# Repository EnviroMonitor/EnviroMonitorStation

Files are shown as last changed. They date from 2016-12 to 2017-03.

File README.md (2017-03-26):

# EnviroMonitorStation
EnviroMonitorStation (part of Smogly aka EnviroMonitor project) is an ESP8266 based, outdoor environmental monitoring station. It includes temperature, humidity, barometric pressure and most importantly, PM2.5, PM10 dust monitoring.

Features:
- PM1.0, PM2.5, PM10 monitoring
- temperature, humidity, barometric pressure monitoring
- heater for exsiccating incoming air for better results in humid conditions (e.g. during autumn and winter)
- post data to custom backend
- post data to Wunderground
- OTA updates for software
- WiFi auto configuration
- 12V/5V powered

Currently EnviroMonitor station is DIY project, we don't provide ability to buy monitoring station, you need to build it yourself.
We also designed [PCB](https://github.com/EnviroMonitor/EnviroMonitorElectronics) and [enclosure](https://github.com/EnviroMonitor/EnviroMonitorEnclosure) so you can easily build your own sensor. Moreover - every piece of the project is Open Source, so you can modify it for your needs.

Please stay tuned, this is work in progress. Prototypes are being tested and we will post usable software and HW design soon.

# Hardware

## Bill of Materials
Below is the list of parts you will need to build monitoring station:

- Wemos D1 mini ESP8266 based development board (example: https://goo.gl/nk0Xvn)
- PMS3003 - Plantower particulate matter sensor detecting PM1.0, PM2.5, PM10 (example: https://goo.gl/ZB6P51)
- BME280 - barometric pressure, temperature and humidity sensor (example: https://goo.gl/bCfaJp)
- Si7021 temperature and humidity sensors (example: https://goo.gl/RCU0Vk)
- DHT22 temperature and humidity sensors (example: https://goo.gl/guQqyB)
- 12V or 5V heat plate (example: https://goo.gl/Pexr5R)
- DC-DC step down power supply module, preferably based on LM2596 (example: https://goo.gl/TbNs1Y)
- AC power supply with 12V DC 1A output (example: https://goo.gl/fVu5LT)
- N-MOSFET, example: AUIRLZ44Z
- 2.54 pitch male pin headers: 2 x 8 pins (Wemos connectors, usually included with Wemos), 1 x 6 pins (PMS3003 connector), 3 x 3 pins (DS, DHT and HEAT DC switch), 1 x 4 pins (I2C bus)
- 2.54 ptich female pin headers: 2 x 8 pins for wemos socket, 1 x 6 pin (to solder instead of original PMS3003 plug)
- 3 x 3.5 mm pitch 2 pin screw terminals
- resistors: 1 x 4.7 kΩ, 1 x 47 kΩ, 1 x 1 kΩ
- [PCB](https://github.com/EnviroMonitor/EnviroMonitorElectronics)
- [enclosure](https://github.com/EnviroMonitor/EnviroMonitorEnclosure)

# Software
## Backend configuration
Before sensor is added to the system, it needs to be registered on the backend side. After registration you will receive couple of parameters:
- sensor ID - used to identify the sensor
- API key - to be able to post and receive data from backend

## Sensor configuration
After sensor is connected to power, it start local AccessPoint for initial configuration. User needs to connect to this AccessPoint and as a next step, familiar HotSpot configuration page should be presented. Using this simple page user can configure:
- sensor ID (generated during sensor registration)
- API access key (generated during sensor registration)
- WiFi network and password to use for sending data
- backend and OTA server address

Once you finish configuration, sensor will reboot, and join configured WiFi network. If there was any error , e.g. wrong password, sensor will again reboot into AccessPoint mode, so you are able to correct configuration.

## How we measure parameters
In every cycle device measures couple of parameters and sends them to EnviroMonitorWe backend. In current version of hardware we measure:
- PM1.0, PM2.5 and PM10
- external temperature and humidity
- external barometric pressure
- temperature and humidity of air incoming to PMS3003 sensor

Before we start measuring PM* parameters, we ensure that incoming air is of accepted parameters: it's humidity and temperature are acceptable. This is required because humid air particles have size similar to PM1 and PM2.5 and can impact precision of measurement. To overcome this effect one could try to figure out how humidity and temperature impacts the measurement (develop mathematical function) or heat the air. We decided to incorporate heating plate near PMS3003 air intake.

Once the air reaches accepted humidity level, we start PM* measurement. Raw data is then sent to backend using simple HTTP GET call. For every monitoring station we can apply individual calibration functions before data is presented.

## Software updates
Every sensor can be updated over-the-air. Once a day sensor sends special request to backend asking for new compiled software image. Using combination of hardware versions and software version for given hardware backend decides to send new image to sensor over HTTP.
Before applying new image we launch pre-update functions ensuring that even if update goes wrong, sensor is safe, e.g. we switch off the heater. Once the update is successful, we use post-update function to get back all sensor features.

# Development
EnviroMonitor project is developed as a community and open source / open hardware project. We use Github for all the development workflow.
EnviroMonitorStation is Arduino based project, but we use [PlatformIO](http://platformio.org/) development environment. Please follow PlatformIO [getting started guide](http://platformio.org/get-started) to set up your environment. We try too keep our code Arduino compatible, so it's possible to use Arduino IDE for development, but we strongly recommend using PlatformIO.

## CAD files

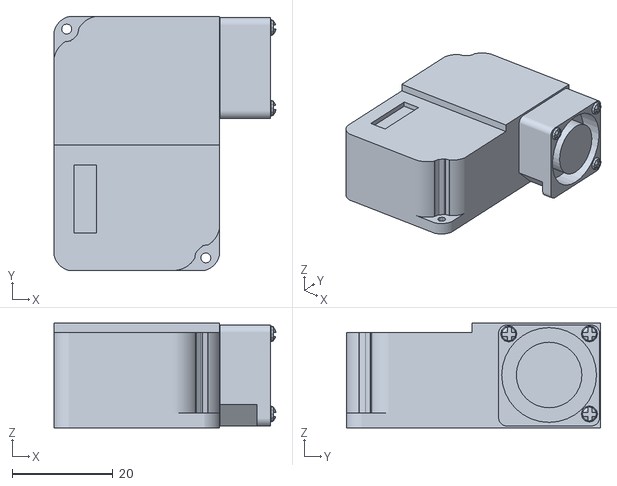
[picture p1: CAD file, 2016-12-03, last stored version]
hardware/enclosure/parts/plantower_pms3003.stl
44.0 x 50.4 x 20.8

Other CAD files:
hardware/3D/parts/plantower_pms3003.obj
hardware/enclosure/parts/plantower_pms3003.obj

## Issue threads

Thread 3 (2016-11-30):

Add external reset button for ESP

zen, 2016-11-30:
ESP8266 is very sensitive for power drops, in some cases it would hang and the only way to reset is using HW button. This button should be added to the project and put on the enclosure for better access

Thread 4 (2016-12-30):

Add support for HTTP OTA updates

zen, 2016-12-30:
Sensor should be able to request new firmware through HTTP OTA procedure.
There should be pre- and post-update actions, specifically turn off the heater.
Sensor should send following data to the server:
- hw_version
- sw_version
- devel (tree or false) - for development type of firmware

Server will decide if there is a new firmware based on hw_version (denoting firmware line) and sw_version (using semver naming).

zen, 2017-02-10:
https://github.com/platformio/framework-arduinoespressif8266/blob/master/doc/ota_updates/readme.md

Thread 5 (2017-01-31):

Provide details how to use

rozie, 2017-01-31:
Add detalis how to use it, where to mount, what to avoid to make data reliable

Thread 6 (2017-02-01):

Add noise level monitor

rozie, 2017-02-01:
Future version could be enhanced by adding noise level monitor https://davidvaleri.wordpress.com/2015/05/25/innovating-with-an-arduino-traffic-light-noise-meter/

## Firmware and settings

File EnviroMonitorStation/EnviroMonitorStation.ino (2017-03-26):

#include <Arduino.h>

/*
####################################################
# EnviroMonitor.ino
# Part of EnviroMonitor project
# https://github.com/EnviroMonitor
# OpenSource Air Quality Monitoring Solution
# Copyright © 2016 by EnviroMonitor
####################################################
*/

#include <ESP8266WiFi.h>
#include <DNSServer.h>
#include <ESP8266WebServer.h>
#include <WiFiManager.h>

#include <ArduinoJson.h>
#include <ESP8266HTTPClient.h>
#include "Config.h"
#include "SmoglyDHT.h"
#include "PMS3003.h"

//set debug mode, use only in testing
#define DEBUG_MODE    true
#define TIME_BETWEEN_METERINGS 2000

#define HEAT_PIN_SWITCH D4
#define TARGET_TEMP 30.0

char apiEndpoint[130] = "http://app.smogly.pl/api/v1/metering/";
char token[130] = "";

SmoglyDHT dht;
PMS3003 pms;

void setup() {
  Serial.begin(115200);
  Serial.println();

  Config config;
  config.mount();

  if (DEBUG_MODE) {
    config.reset();
  }

  pinMode(HEAT_PIN_SWITCH, OUTPUT);

  config.read("/config.json");

  WiFiManagerParameter custom_apiEndpoint("apiEndpoint", "Smogly URL", apiEndpoint, 130);
  WiFiManagerParameter custom_token("token", "Token", token, 130);

  WiFiManager wifiManager;
  wifiManager.addParameter(&custom_apiEndpoint);
  wifiManager.addParameter(&custom_token);

  if (!wifiManager.autoConnect("Smogly Air Quality Monitor")) {
    Serial.println("Failed to connect and hit timeout");
    delay(3000);
    ESP.reset();
    delay(5000);
  }

  strcpy(apiEndpoint, custom_apiEndpoint.getValue());
  strcpy(token, custom_token.getValue());

  Serial.println("Successfully connected to WiFi network");

  config.save("/config.json");

  Serial.print("Local IP set to: ");
  Serial.println(WiFi.localIP());
  Serial.println("Initializing DHT");
  dht.setup();
  Serial.println("Initializing PMS");
  pms.init();
  delay(TIME_BETWEEN_METERINGS);
}

void loop() {
    // Reading temperature or humidity takes about 250 milliseconds!
    // Sensor readings may also be up to 2 seconds 'old' (its a very slow sensor)
    float h = dht.readHumidity();
    // Read temperature as Celsius (the default)
    float t = dht.readTemperature();

    pms.read();
    long pm25 = pms.pm25;
    long pm10 = pms.pm10;

    // Check if any reads failed and exit early (to try again).
    if (isnan(h) || isnan(t)) {
      Serial.println("Failed to read from DHT sensor!");
      return;
    }

    if (t >= TARGET_TEMP) // we're going to measure humidity instead of temp
    {
      digitalWrite(HEAT_PIN_SWITCH, LOW);
      Serial.print(t);
      Serial.print("\tHeater OFF\n");
    } else {
      digitalWrite(HEAT_PIN_SWITCH, HIGH);
      Serial.print(t);
      Serial.print("\tHeater ON\n");
    }

    String output = createPayload(h,t, pm25, pm10);
    HTTPClient http;
    http.begin(apiEndpoint);
    http.addHeader("Content-Type", "application/json");
    http.POST(output);
    http.end();
    // Wait a few seconds between measurements.
    delay(TIME_BETWEEN_METERINGS);
}

String createPayload(float h, float t, long pm25, long pm10)
{
  StaticJsonBuffer<300> jsonBuffer;
  JsonObject& root = jsonBuffer.createObject();
  root["pm01"] = 0;
  root["pm25"] = pm25;
  root["pm10"] = pm10;
  root["temp_out1"] = t;
  root["temp_out2"] = 0;
  root["temp_out3"] = 0;
  root["temp_int_air1"] = 0;
  root["hum_out1"] = h;
  root["hum_out2"] = 0;
  root["hum_out3"] = 0;
  root["hum_int_air1"] = 0;
  root["rssi"] = 0;
  root["bpress_out1"] = 0;
  root["hw_id"] = "0";
  root["token"] = token;
  String output;
  root.printTo(output);
  return output;
}

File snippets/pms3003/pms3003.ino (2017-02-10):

#include <Arduino.h>

/*
This example demonstrate how to read pm1, pm2.5 and pm10 values from PMS 3003 air condition sensor.

Inspired by:
 https://github.com/brucetsao/eParticle/blob/master/PMS3003AirQualityforLinkIt/PMS3003AirQualityforLinkIt.ino and Dariusz Borowski code https://bitbucket.org/dariusz-borowski/obywatelski-monitoring-pylu

 PMS 3003 pin map is as follow:
    PIN1  :VCC, connect to 5V
    PIN2  :GND, connect to GND from power source
    PIN3  :SET, 0:Standby mode, 1:operating mode
    PIN4  :RXD :Serial RX
    PIN5  :TXD :Serial TX
    PIN6  :RESET
    PIN7  :NC
    PIN8  :NC

 Data format of PMS3003 is 24 one byte messages:
 Header 1
 Header 2
 Control bit high = 2 x 9 + 2
 Control bit low
 PM1.0 high standard particle
 PM1.0 low standard particle
 PM2.5 high standard particle
 PM2.5 low standard particle
 PM10 high standard particle
 PM10 low standard particle
 PM1.0 high
 PM1.0 low
 PM2.5 high
 PM2.5 low
 PM10 high
 PM10 low
 Reserved 1 high
 Reserved 1 low
 Reserved 2 high
 Reserved 2 low
 Reserved 3 high
 Reserved 4 low
 Checksum high - sum of 9 previous readings
 Checksum low


 In this example, we only use Serial to get PM 2.5 value.

 The circuit:
 * RX is digital pin 6 (connect to TX of PMS 3003)
 * TX is digital pin 7 (connect to RX of PMS 3003)
 * SET is digital pin 5 (connect to SET of PMS 3003)

 */

#include <SoftwareSerial.h>

#define DEBUG true

#define PMS_PIN_SET D5
#define PMS_PIN_RX D6
#define PMS_PIN_TX D7
#define PMS_PIN_RST D8
#define PMS_BAUDRATE 9600

// PMS3003 Data format
#define PMS_HEADER1 0 //0x42
#define PMS_HEADER2 1 // 0x4d
#define PMS_COMMAND1 2 // frame lenght high
#define PMS_COMMAND2 3 // frame lenght low
#define PMS_PM1C_HIGH 4
#define PMS_PM1C_LOW 5
#define PMS_PM25C_HIGH 6
#define PMS_PM25C_LOW 7
#define PMS_PM10C_HIGH 8
#define PMS_PM10C_LOW 9
#define PMS_PM1_HIGH 10
#define PMS_PM1_LOW 11
#define PMS_PM25_HIGH 12
#define PMS_PM25_LOW 13
#define PMS_PM10_HIGH 14
#define PMS_PM10_LOW 15
#define PMS_RES1_HIGH 16
#define PMS_RES1_LOW 17
#define PMS_RES2_HIGH 18
#define PMS_RES2_LOW 19
#define PMS_RES3_HIGH 20
#define PMS_RES3_LOW 21
#define PMS_CHECKSUM_HIGH 22
#define PMS_CHECKSUM_LOW 23

SoftwareSerial pms(PMS_PIN_RX, PMS_PIN_TX); // Initialize serial communiation with PMS 3003

#define pmsDataLen 24 // according to spec PMS3003 has 24 bytes long message
uint8_t buf[pmsDataLen];
int idx = 0;
long pm10 = 0;
long pm25 = 0;

void setup() {
  Serial.begin(115200);
  pms.begin(PMS_BAUDRATE); // PMS 3003 UART has baud rate 9600
  pinMode(PMS_PIN_SET, OUTPUT);
  digitalWrite(PMS_PIN_SET, HIGH);
}

void loop() { // run over and over
  uint8_t c = 0;
  idx = 0;
  memset(buf, 0, pmsDataLen);

  //digitalWrite(PMS_PIN_SET, HIGH);
  delay(1000);

  while (true) {
    while (c != 0x42) {
      while (!pms.available());
      c = pms.read();
    }
    while (!pms.available());
    c = pms.read();
    if (c == 0x4d) {
      // now we got a correct header)
      buf[idx++] = 0x42;
      buf[idx++] = 0x4d;
      break;
    }
  }

  while (idx != pmsDataLen) {
    while(!pms.available());
    buf[idx++] = pms.read();
  }
  long pms_checksum = word(buf[PMS_CHECKSUM_HIGH], buf[PMS_CHECKSUM_LOW]);
  long pms_calc_checksum = buf[PMS_HEADER1] + buf[PMS_HEADER2] +
                            buf[PMS_COMMAND1] + buf[PMS_COMMAND2] +
                            buf[PMS_PM1C_HIGH] + buf[PMS_PM1C_LOW] +
                            buf[PMS_PM25C_HIGH] + buf[PMS_PM25C_LOW] +
                            buf[PMS_PM10C_HIGH] + buf[PMS_PM10C_LOW] +
                            buf[PMS_PM1_HIGH] + buf[PMS_PM1_LOW] +
                            buf[PMS_PM25_HIGH] + buf[PMS_PM25_LOW] +
                            buf[PMS_PM10_HIGH] + buf[PMS_PM10_LOW] +
                            buf[PMS_RES1_HIGH] + buf[PMS_RES1_LOW] +
                            buf[PMS_RES2_HIGH] + buf[PMS_RES2_LOW] +
                            buf[PMS_RES3_HIGH] + buf[PMS_RES3_LOW];


  if (pms_calc_checksum == pms_checksum) {
    Serial.print("Checksum correct: ");
    Serial.print(pms_checksum);
    Serial.print(" / ");
    Serial.println(pms_calc_checksum);
  }
  else {
    Serial.print("Checksum incorrect: ");
    Serial.print(pms_checksum);
    Serial.print(" / ");
    Serial.println(pms_calc_checksum);

    if DEBUG {
      Serial.println("Raw data dump:");
      for (int i=0; i< pmsDataLen;i++) {
        Serial.print(buf[i]);
        Serial.print(" ");
      }
    }
    Serial.println();
    }

  pm25 = word(buf[12], buf[13]);
  pm10 = word(buf[14], buf[15]);

  Serial.print("pm2.5: ");
  Serial.print(pm25);
  Serial.print(" pm10: ");
  Serial.println(pm10);
  delay(4000);
}

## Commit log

2016-05-29 TravisCI: removed ArduinoOTA library
2016-11-13 added peliminary Fritzing/PCB design
2016-11-20 Added initial electrical design
    [EnviroMonitor.fzz]
2016-11-25 corrected PCB design
    [EnviroMonitor.fzz]
2016-11-25 Added README.md
    Initial README.md with HW, BOM and basic information
2016-11-26 Many general hardware changes
    - DS moved to pin header
    - optimized PCB (60mm x 60mm)
    - all pads moved to bottom, added many through holes
    - Custom parts added: Wemos D1 mini with fixed pads, DS with smaller footprint
    - added Gerber export
    [EnviroMonitor.fzz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]
2016-11-26 Moved 'documentation' into 'hardware'
    [EnviroMonitor.fzz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]
2016-11-30 PCB optimisations
    [EnviroMonitor.fzz]
2016-12-03 repository reorganisation
    [EnviroMonitor.fzz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]
2016-12-03 added PMS3003 3D model for EnviroMonitor enclosure design
    [plantower_pms3003.obj, plantower_pms3003.stl]
2016-12-11 Moved 3D model to enclosure
    [plantower_pms3003.obj, plantower_pms3003.stl]
2016-12-26 Description of socket view
2017-01-01 Removed redundant wires in breadboard view
    [EnviroMonitor.fzz]
2017-01-01 Added Gerber design files
2017-02-09 removed migrated hardware directory
    [EnviroMonitor.fzz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]
2017-02-10 Migrated project to PlatformIO
    - generated PlatformIO configuration
    - modified Travis CI configuration to use PIO
    - added PIO compatible gitignore
    - moved snippets to separate repository
    - added Arduino IDE compatibility layer
    - changed README to reflect migration to PIO
2017-02-10 fixing Bill Of Materials + adding goo.gl links to aliexpress.com
2017-02-10 Adding 1A to power supply.
2017-03-26 updated BOM to contain all parts
2017-03-26 more updates to BOM
2017-03-26 Add heat plate controller
2017-03-26 Disable turning heating on automatically
